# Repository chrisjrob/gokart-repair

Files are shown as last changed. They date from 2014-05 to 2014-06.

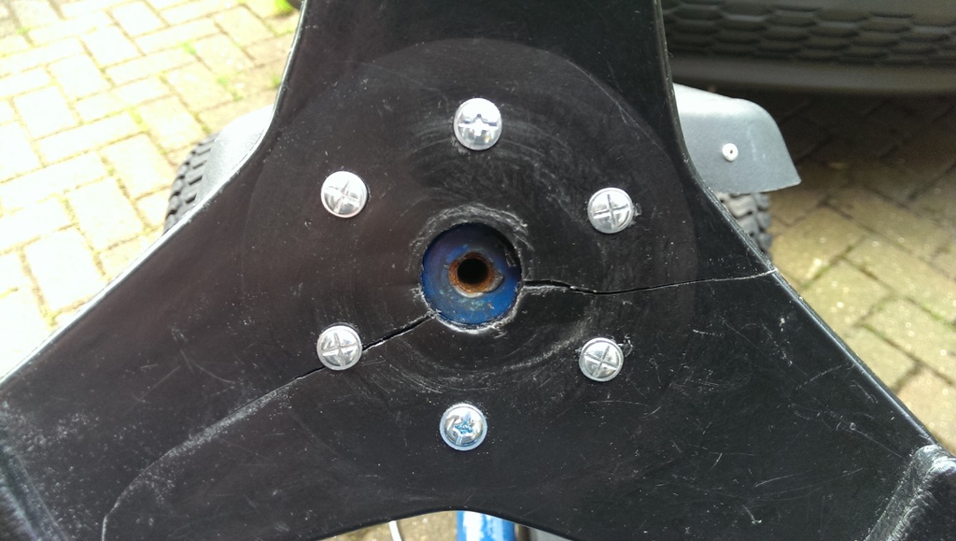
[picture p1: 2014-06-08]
IMAG0994.jpg

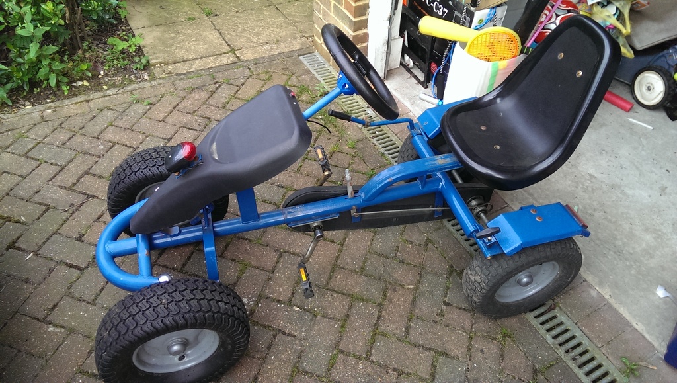
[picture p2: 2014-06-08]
IMAG0988.jpg

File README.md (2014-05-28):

Go-Kart Repair
==============

Copyright (C) 2013 Christopher Roberts

Licensed under the [GPL v3 Licence](https://github.com/chrisjrob/gokart-repair/blob/master/LICENCE.md "Read licence")

Description
-----------
Designed in OpenSCAD.
This is a repair to a Go-Kart's steering wheel, to enable it to be reattached to the steering bolt.
This is only suitable for go-karts that have a nut on the end of the steering shaft. 
This model provides a replacement junction between the steering nut and the steering wheel.

The model has an option of adding strengthening pin holes around the nut (see Credits below). 
Interestingly, if the pin holes do not protrude from at least one end of the model, the slicing program removes the pinholes entirely.

Status
------
Complete.

Instructions
------------
* Edit SCAD file with your preferred parameters, in particular the steering nut size.
* Compile and export to STL.
* Slice and print.

Credits
-------
Thank you to [Wildseyed Cabrer](https://plus.google.com/103153642711282733992) for suggesting that I do away with the buttresses of [v1](https://github.com/chrisjrob/gokart-repair/tree/v1) and instead design a solid cylinder. 
Of particular interest was his suggestion to use pinholes around the nut hole, to force the slicing program to add reinforcement; which has now been implemented in this design.
Thank you to [Andreas Thorn](https://plus.google.com/+AndreasThorn1) for reminding me to use the $fn = 6 for the chamferring of the nut hole, as I had for the nut hole itself.

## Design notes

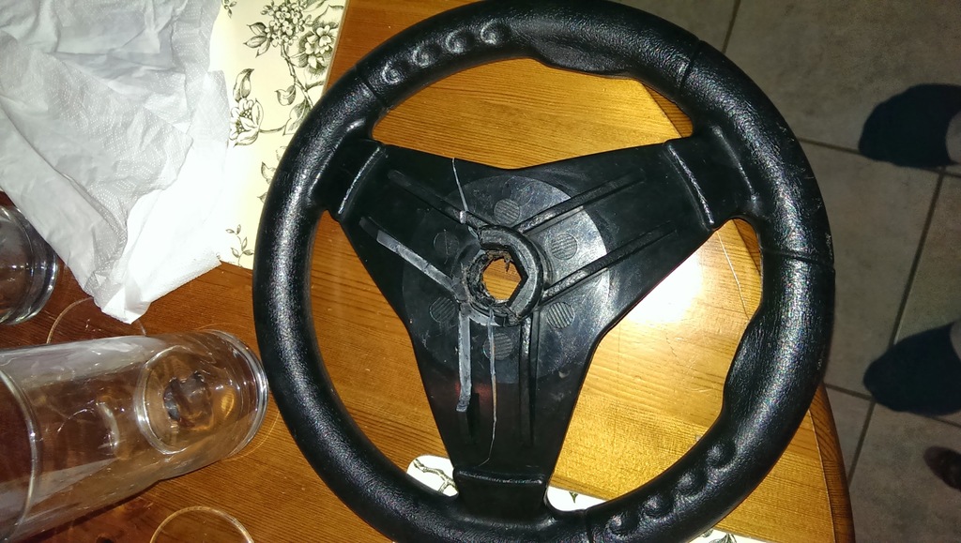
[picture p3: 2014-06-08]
IMAG0530.jpg

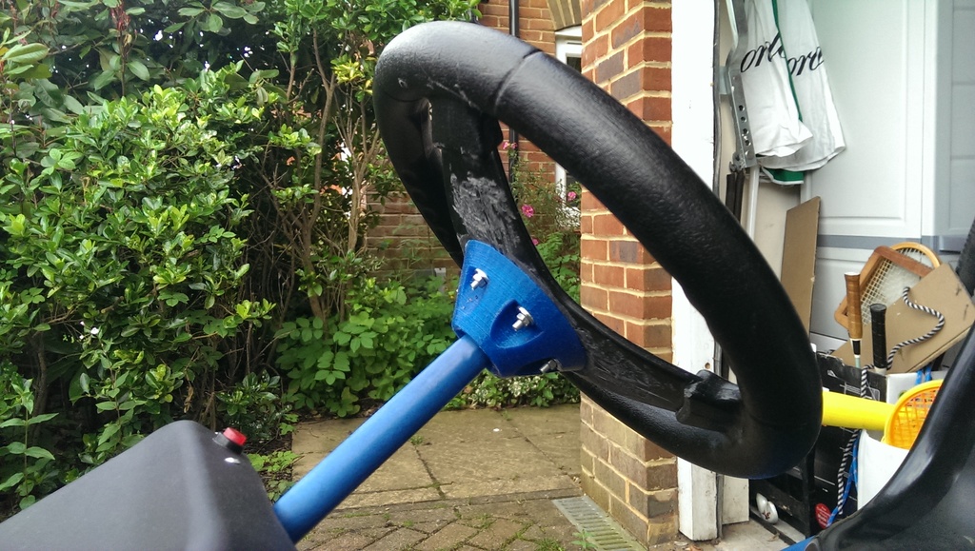
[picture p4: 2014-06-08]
IMAG0989.jpg

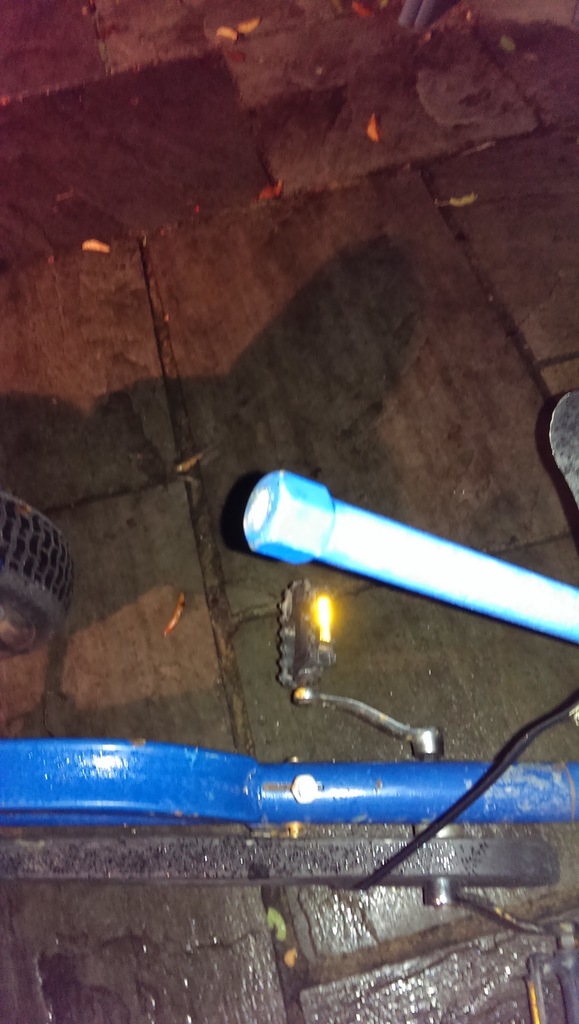
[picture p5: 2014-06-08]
IMAG0534.jpg

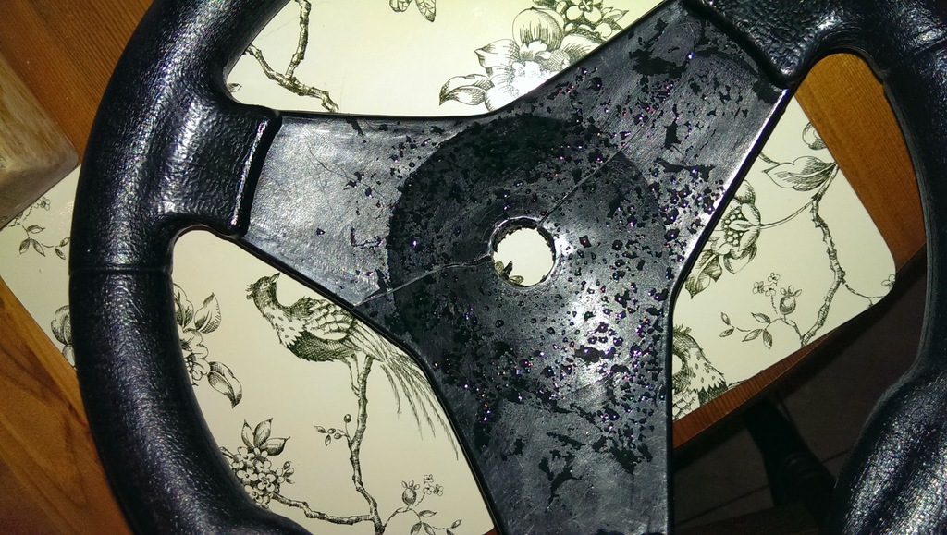
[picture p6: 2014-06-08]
IMAG0532.jpg

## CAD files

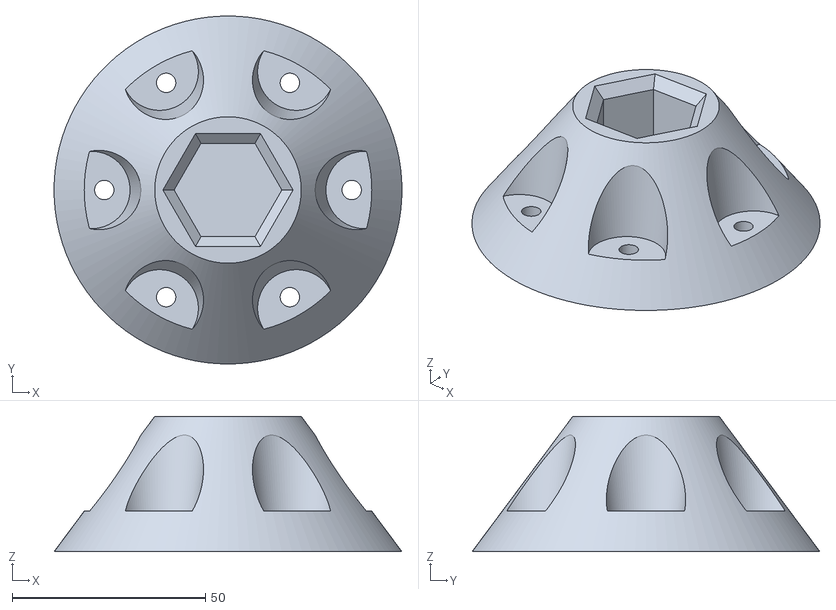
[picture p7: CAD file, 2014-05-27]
gokart-repair.stl
90.0 x 90.0 x 35.0

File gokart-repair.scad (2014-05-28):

// gokart-repair.scad
// OpenSCAD Document
// 
// Copyright (C) 2013 Christopher Roberts
//
// This program is free software: you can redistribute it and/or modify
// it under the terms of the GNU General Public License as published by
// the Free Software Foundation, either version 3 of the License, or
// (at your option) any later version.
// 
// This program is distributed in the hope that it will be useful,
// but WITHOUT ANY WARRANTY; without even the implied warranty of
// MERCHANTABILITY or FITNESS FOR A PARTICULAR PURPOSE.  See the
// GNU General Public License for more details.
// 
// You should have received a copy of the GNU General Public License
// along with this program.  If not, see <http://www.gnu.org/licenses/>.

// Printer accuracy
printer_layer_height    = 0.3; //mm
shim                    = 0.1; //mm

// Nut parameters
// What you need is the diameter of the circle around the nut
// a. you may enter the nut size (i.e. the spanner size):
nut_size             = 24; //mm - the nut "spanner" size
// b. or you may enter the nut diameter (which will always be twice once of the side lengths):
nut_diameter         = (((nut_size/2) / cos(30)) *2) + shim; //mm - the circular diameter not nut size
// nut_diameter      = 27.8736; //mm - uncomment line to over-ride calculation from nut size

// Base parameters
base_diameter_large  = 90; //mm
base_diameter_small  = 83; //mm

// Core parameters
core_diameter_large  = base_diameter_large/2; //mm
core_diameter_small  = nut_diameter + 10; //mm
core_height          = 35; //mm

// Other parameters
hole_diameter        = 5; //mm
washer_diameter      = 10; //mm
pin_diameter         = 0.3; //mm
circular_precision   = 100;

// Selection:
// 1 = the whole thing
// 2 = nut test - for checking actual size of nut hole
select = 1;

// Strengthening Pin Holes
// 0 = Off, 1 = On
pin_holes = 0;

echo("Nut diameter is:");
echo(nut_diameter);

module repair() {

    difference() {

        // Things that exist
        union() {
            // The core - the cone part that will contain the nut
            translate( v = [0, 0, 0] ) {
                cylinder( r1 = base_diameter_large/2, r2 = core_diameter_small/2, core_height, $fn = circular_precision );
            }
        }

        // Things that don't exist
        union() {
            // The nut hole
            translate( v = [0, 0, +shim] ) {
                cylinder( r = nut_diameter/2, h = core_height, $fn = 6 );
            }
            // Chamferring nut entrance
            translate( v = [0, 0, core_height - 3]) {
                cylinder(r2=nut_diameter/2 + 3,r1=nut_diameter/2,h=3+shim,$fn=6);
            }
            if (select == 1) {
                // Bolt holes and washers around base
                for (a = [0 : 60 : 360] ) {
                    rotate( a = [0, 0, a] ) {
                        // Bolt holes
                        translate( v = [ (base_diameter_small - (base_diameter_small - core_diameter_large)/2)/2, 0, -shim] ) {
                            cylinder( r = hole_diameter/2, core_height + 0.2, $fn = circular_precision );
                        }
                        // Washer holes
                        translate( v = [ (base_diameter_small - (base_diameter_small - core_diameter_large)/2)/2 +washer_diameter/3, 0, core_height * 0.3] ) {
                            scale([ 1, 1, 1 ]) {
                                cylinder( r1 = washer_diameter, r2 = washer_diameter * 1.5, core_height + 0.2, $fn = circular_precision );
                            }
                        }
                    }
                }
                // Strengthening pin holes
                if (pin_holes == 1) {
                    for (a = [30 : 60 : 360] ) {
                        rotate( a = [0, 0, a] ) {
                            for (y = [-nut_diameter/4 : nut_diameter/8 : nut_diameter/4] ) {
                                translate( v = [ core_diameter_small * 0.43, y, -shim] ) {
                                    # cylinder( r = pin_diameter/2, core_height - printer_layer_height * 3, $fn = circular_precision );
                                }
                            }
                        }
                    }
                }
            }
        }
    
    }

}

if (select == 1) {
    repair();
}

if (select == 2) {
    difference() {
        union() {
            translate( [0, 0, -core_height * 0.85] ) {
                repair();
            }
        }
        union() {
            translate( [-base_diameter_large/2, -base_diameter_large/2, -core_height] ) {
                # cube( [base_diameter_large, base_diameter_large, core_height] );
            }
        }
    }
}

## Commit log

2013-11-24 initial version - may need tweaking
    [gokart-repair.scad, gokart-repair.stl]
2013-11-24 tweak to stop buttress protruding beyond base edge
    [gokart-repair.scad, gokart-repair.stl]
2013-11-25 replaced 0.1 with shim variable
    [gokart-repair.scad]
2013-11-25 Simplified chamferring of nut entrance - thank you Andreas Thorn, and removed redundant nut module
    [gokart-repair.scad]
2013-11-25 improved nut entrance chamferring - thank you Andreas Thorn for the suggestion
    [gokart-repair.stl]
2013-12-04 make repair solid for strength
    [gokart-repair.scad]
2013-12-07 add a selection to print just a top slice of the nut hole for real world testing
    [gokart-repair.scad]
2013-12-08 enable calculation from nut size and increase pin hole size to force slicing to recognise
    [gokart-repair.scad, gokart-repair.stl]
2014-05-24 increase nut size
    [gokart-repair.scad]
2014-05-27 tweak size of nut and remove unnecessary components from test print
    [gokart-repair.scad]
2014-05-27 shorten strengthening pin holes so not visible top or bottom
    [gokart-repair.scad]
2014-05-27 further nut hole size tweak
    [gokart-repair.scad, gokart-repair.stl]
2014-05-27 tweaked nut hole size again
    [gokart-repair.stl]
2014-05-27 pin holes have to exit side or slic3r omits them
    [gokart-repair.scad]
2014-05-28 Removed excessive padding around nut and parameterised pin holes.
    [gokart-repair.scad]
2014-05-28 Set status to complete, improved instructions and added pin hole info.
